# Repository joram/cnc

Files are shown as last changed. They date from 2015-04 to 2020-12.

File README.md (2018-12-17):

# CnC project
This is a scratchpad repos for a homemade CnC machine.

![CnC Image](https://lh3.googleusercontent.com/Xgm548oeinaSXzI4gLVN7XoVqA7QdndGtPZtI5exSCHnF55dnqytLXTcyp7rUA87UzZo4A43uE3hCB0zz5r6ulhqA-s1Z9l3nHRdatXveawGpr5k0o3v1wGfOVFIFiJOtZK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)

## Documentation
- [construction](/docs/construction.md)
- [how to](/docs/how_to.md)
- [gotchas](/docs/gotchas.md)
- [photos](https://photos.app.goo.gl/LfezZGhpHDF61HZo7)

## Potential Future Projects
- button (for test carves)
- alphabet blocks
- wall-o-faces with [photogrammetry](./docs/photogrammetry.md)
- wooden keyboard keys
- replacement plates for CnC machine

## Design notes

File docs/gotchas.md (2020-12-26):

# Gotchas
These are notes around different types of failures in the carving process.

## Grbl not responding
- run the protoneer image [here](https://wiki.protoneer.co.nz/Raspberry_Pi_CNC_User_Interface_SD_Card_Image_V5.00)
- on the desktop there is a script `setup <something>.sh` run it.
- flash hte firmware

## cncjs not starting on boot
setup pm2 as these instructions show [here](https://cnc.js.org/docs/rpi-setup-guide/)

## Axis Slippage
![axis slippage example](https://lh3.googleusercontent.com/Vf0Y8VVEjJ2XM6gfTe-zDjV55Q0uxVouj7I30cJ42lzLdh7OGVdnMimoT3kyHdOLQLK_bFZwpQ-9uzBsDDFnQawyxHjg7FAltyq_YpEZxONzpE0hcR4VNmeD5QOT6cWFXOD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)
This was caused by the axis max speed being configured too fast. Fixed by using grbl console, `$$` to show the settings, and reducing the max speed with $111=200 (setting max y axis speed to be slower).

## Stock Slippage
![stock slippage example](https://lh3.googleusercontent.com/6YKA4u-dw940YjIze_3f_o0F8SFl5KL5prnh7_Do42InjSy5k3oyd3c-yxGbHiALIYOR6loodVLiBiFj7hbNlPa4jSL3y-EL85IqTiSvR1EXWWCtUjLUTIdA_onvhK02feY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)
This was caused by the piece of wood being milled not being fixed securly enough to the bed. Fixed by attaching it securely.

## Stock Tilting
![stock tilting example](https://lh3.googleusercontent.com/TAGg_NbH2bvvy6UUZl_5ei28SwbjK26DU1DIArqDUK3FyZzLX3r0ULFSAph8NOIbOFqiKsIxAeU5NCbYqucJ9vn9xD515G7MOkKrXSUOOhmWLBMeKNv9lEcPw5b-VvpMQmR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)
Same as `Stock Slippage`

## Model Origin (instead of stock)
![model origin example](https://lh3.googleusercontent.com/5Rb-ZSzZFDaninfDXt5FVSv54ZFPO3YPs4qB9GPZXhAcuzTi9tC0n2zDV6-qIzB_at-JtLGqfSBiFv2VKmg3dzT2kL5WLJw5bpFtXIv03030YuJ1XTXKcDOQkVxNNPNzoSa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)
This was caused by selecting part of the model's bounding box as the origin instead of the stock's.
Fixed by picking the origin to be a recognizable edge of the bounding box, with a significant enough headroom on the stock to account for any sort of tilt.

## Why is the toolpath not generating!?
right click mesh, and then "meshg to brep"

## Studdering
Don't randomly turn the potentiometers, you're bound to make it worse. Calibrate the current limit with the instructions.
The Pololu driver docs [here](https://www.pololu.com/product/2133) show
```
To achieve high step rates, the motor supply is typically much higher than would be permissible without active current limiting. For instance, a typical stepper motor might have a maximum current rating of 1 A with a 5Ω coil resistance, which would indicate a maximum motor supply of 5 V. Using such a motor with 12 V would allow higher step rates, but the current must actively be limited to under 1 A to prevent damage to the motor.

The DRV8825 supports such active current limiting, and the trimmer potentiometer on the board can be used to set the current limit. You will typically want to set the driver’s current limit to be at or below the current rating of your stepper motor. One way to set the current limit is to put the driver into full-step mode and to measure the current running through a single motor coil without clocking the STEP input. The measured current will be 0.7 times the current limit (since both coils are always on and limited to approximately 70% of the current limit setting in full-step mode).

Another way to set the current limit is to measure the voltage on the “ref” pin and to calculate the resulting current limit (the current sense resistors are 0.100Ω). The ref pin voltage is accessible on a via that is circled on the bottom silkscreen of the circuit board. The current limit relates to the reference voltage as follows:

Current Limit = VREF × 2

So, for example, if you have a stepper motor rated for 1 A, you can set the current limit to 1 A by setting the reference voltage to 0.5 V.

Note: The coil current can be very different from the power supply current, so you should not use the current measured at the power supply to set the current limit. The appropriate place to put your current meter is in series with one of your stepper motor coils.
```
### For our stepper motors
```
350mA for the nema17 steppers
0.35/2 = vref = 0.175

2.8a for the nema23 stepper
2.8/2 = fref = 1.4

```
## An Axis Stopping Completely
This is because the driver overheated.
We now have heatsinks on the drivers, check that they are still attached.
The current limit may be too high (see how to calibrate in the `Studdering` section), and lower that value a bit.
The side effect of lowering hte vref is that axis provides less power.

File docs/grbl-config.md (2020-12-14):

```
$0=25 (Step pulse time, microseconds)
$1=50 (Step idle delay, milliseconds)
$2=0 (Step pulse invert, mask)
$3=0 (Step direction invert, mask)
$4=0 (Invert step enable pin, boolean)
$5=0 (Invert limit pins, boolean)
$6=0 (Invert probe pin, boolean)
$10=0 (Status report options, mask)
$11=0.010 (Junction deviation, millimeters)
$12=0.002 (Arc tolerance, millimeters)
$13=0 (Report in inches, boolean)
$20=0 (Soft limits enable, boolean)
$21=1 (Hard limits enable, boolean)
$22=0 (Homing cycle enable, boolean)
$23=0 (Homing direction invert, mask)
$24=25.000 (Homing locate feed rate, mm/min)
$25=500.000 (Homing search seek rate, mm/min)
$26=250 (Homing switch debounce delay, milliseconds)
$27=1.000 (Homing switch pull-off distance, millimeters)
$30=1000 (Maximum spindle speed, RPM)
$31=0 (Minimum spindle speed, RPM)
$32=0 (Laser-mode enable, boolean)
$100=50.000 (X-axis travel resolution, step/mm)
$101=100.000 (Y-axis travel resolution, step/mm)
$102=50.000 (Z-axis travel resolution, step/mm)
$110=300.000 (X-axis maximum rate, mm/min)
$111=200.000 (Y-axis maximum rate, mm/min)
$112=200.000 (Z-axis maximum rate, mm/min)
$120=3.000 (X-axis acceleration, mm/sec^2)
$121=3.000 (Y-axis acceleration, mm/sec^2)
$122=3.000 (Z-axis acceleration, mm/sec^2)
$130=1000.000 (X-axis maximum travel, millimeters)
$131=1000.000 (Y-axis maximum travel, millimeters)
$132=15.000 (Z-axis maximum travel, millimeters)
```

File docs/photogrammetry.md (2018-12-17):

# Photogrammetry
The process of taking photos and making a 3D model.

## links
https://www.prusaprinters.org/photogrammetry-3d-scanning-just-phone-camera/
https://demuc.de/colmap/

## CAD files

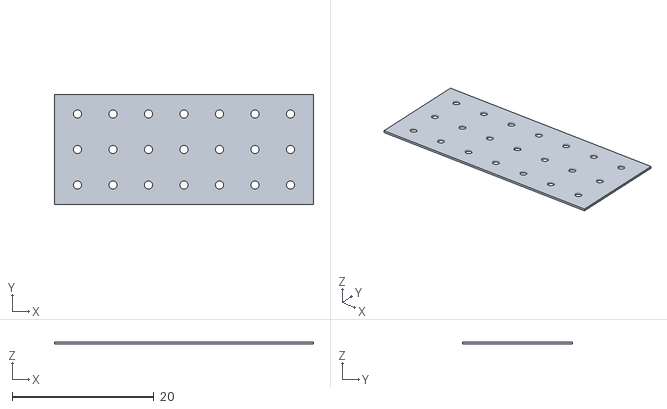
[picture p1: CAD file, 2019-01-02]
gcode/cnc_bed_2.stl
36.5 x 15.5 x 0.3

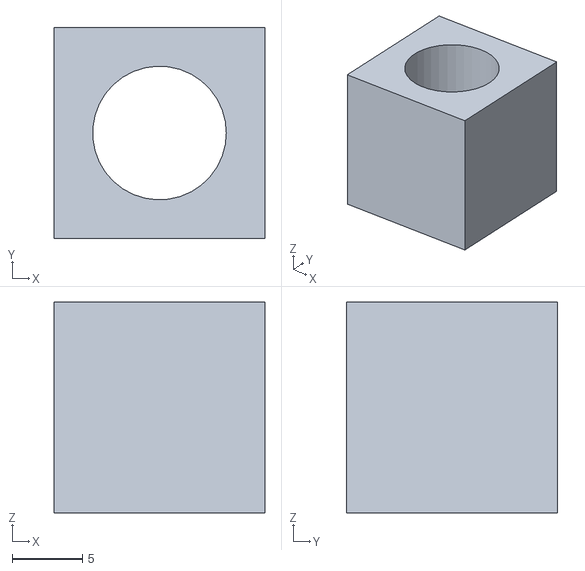
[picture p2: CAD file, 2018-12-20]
gcode/dowl_test.stl
15.0 x 15.0 x 15.0

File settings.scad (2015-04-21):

bed_height = 55; //mm
bed_width = 300; //mm
bed_depth = 300; //mm
y_tray_depth = 80; // mm
nema17_width = 42.2;

//GT2
belt_width=6; 
belt_thickness=5; // ? 
tooth_height=5; // ?
tooth_spacing=2;

// RODS

threaded_rod_diameter = 9;
threaded_rod_diameter_horizontal = 9;
smooth_bar_diameter = 9;
smooth_bar_diameter_horizontal = 9;

// Nuts and bolts

m8_diameter = 9;
m8_nut_diameter = 15.7;

m4_diameter = 5.5;
m4_nut_diameter = 10.6;

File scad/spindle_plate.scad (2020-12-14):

include <components/spindle_mount.scad>;
include <components/sc8uu.scad>;

spindle_plate_w = 150;
spindle_plate_h = 200;
spindle_plate_thickness = 10;

module spindle_plate(show_bolts=false, show_mounts=false){
    dx = spindle_plate_w/2 - sc8uu_l/2;
    dy = spindle_plate_h/2  - sc8uu_w/2;
    dz = -sc8uu_h/2;
    sc8uu_offsets = [
        [ dx,-dy, dz],
        [ dx, dy, dz],
        [-dx,-dy, dz],
        [-dx, dy, dz],
        [  0,  0, dz],
    ];

    if(show_bolts==true){
        translate([0, -spindle_plate_h/4, spindle_plate_thickness]) spindle_mount(true);
        for(t=sc8uu_offsets){
            translate(t) sc8uu(true);
        }
    }
    
    if(show_bolts==false){
        difference(){
            translate([0, 0, spindle_plate_thickness/2]) cube([spindle_plate_w, spindle_plate_h, spindle_plate_thickness], true);
            spindle_plate(true);
        }
    }

    if(show_mounts==true){
        %union(){
            translate([0, -spindle_plate_h/4, spindle_plate_thickness]) union(){
                translate([0,0,spindle_mount_d/2]) spindle();
                spindle_mount();
            }
            for(t=sc8uu_offsets){
                translate(t) sc8uu();
            }
        }
    }

}



//projection(cut = false) translate([spindle_plate_w/2,spindle_plate_h/2,0]) spindle_plate(true, false);
//spindle_plate(false, true);

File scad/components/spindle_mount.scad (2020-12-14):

spindle_d = 52;
spindle_l = 186;
collet_l = 48;
collet_d = 16;

spindle_mount_w = 91;
spindle_mount_h = 41;
spindle_mount_d = 67;


module spindle(){
    translate([0, collet_l-10]) rotate([90]) cylinder(h=spindle_l-collet_l, d=spindle_d, center=true);
    translate([0, -collet_l/2-10]) rotate([90]) cylinder(h=collet_l, d=collet_d, center=true);            
}

module spindle_mount(show_bolts=false){
    bolt_d = 6;
    bolt_x = 77;
    bolt_y = 26;
    offsets = [
        [ bolt_x/2, bolt_y/2],
        [ bolt_x/2,-bolt_y/2],
        [-bolt_x/2, bolt_y/2],
        [-bolt_x/2,-bolt_y/2],
    ];

    if(show_bolts == true){
        translate([0,0,spindle_mount_d/2]) union(){
//            spindle();
            for(t=offsets){
                translate(t) cylinder(h=spindle_mount_d*2, d=bolt_d, center=true);
            }
        }
    }

    // for human eyes only
    if(show_bolts==false){
        difference(){
            translate([0,0,spindle_mount_d/2]) cube([spindle_mount_w, spindle_mount_h, spindle_mount_d], true);
            spindle_mount(true);
        }
    }
}

//spindle_mount();
//%spindle_mount(true);

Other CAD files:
scad/arm-plate.scad
axles.scad
bearings.scad
project.scad
scad/all-plates.scad
scad/components/kp08.scad
scad/components/nema17.scad
scad/components/sc8uu.scad
scad/components/sk8.scad
scad/horizontal-plate.scad
scad/old/axles.scad
scad/old/bearings.scad
scad/old/project.scad
scad/old/settings.scad
scad/old/sliding_tray.scad
scad/vertical-plate.scad
sliding_tray.scad

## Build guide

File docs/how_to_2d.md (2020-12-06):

# How To (2D)

## Make SVG
use your tool of choice
- I've heard inkscape is good
- OR: using any photo editing tool and then converting to svg (web tool [pngtosvg.com](https://www.pngtosvg.com/))
- a 380px square will fit on a alphabet cube.

## Make GCODE
use [jscut.org](http://jscut.org/jscut.html) tool.
- set 300 DPI
- cut depth 0.05 to start, go up to 0.1 per layer
- don't lie about your bit size. it's 3.175 for the default. use calipers if oyu are using a different bit

## Setup Machine
place the block firmly attached to the board
- for small blocks use the clamp
- for big sheets clamp or screw to table

## Mill
- manually drive the bit to the top left corner of your work, barely touching the material.
- zero out the machine
- manually drive the bit to the bottom left of the work (as seen in the UI)
- make sure it will fit the material
- home XY, then home Z
- turn on the spindle
- press play

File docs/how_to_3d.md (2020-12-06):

# How To (3D)
There are three phases to building an object with a CnC machine: modeling, caming, carving

## Modeling
Use whatever you want to make an STL file (or anything that can be imported to fusion 360)

## Caming

## Carving

### Initial setup
- visit [cncJS](http://192.168.1.10:8000) (john with reg password)
- on the left, top right: choose grbl, and connect to ttyS0

### Zero-ing Workspace
There are two coordinate systems: machine and workspace.
Machine origin (0,0,0) is wherever the bit was when the machine was turned on.
Workspace origin is the position in relation to your stock piece (what you are gonna carve).
Before each carve, you want to zero out the workspace origin:
 - reset then unlock
 - keyboard button (to manually control)
 - finger to position for piece you are carving
 - set work position to zero/zero/zero

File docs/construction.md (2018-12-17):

## Parts List

### Electronic
|  name | #  |  unit cost  | total cost |
|:---|---:|---|---|
| nema17 stepper motors | 3x | [$00.00](https://www.adafruit.com/product/324) ||
| milling motor | 1x | [here]() ||
| Raspberry PI 3 | 1x | [here](https://www.amazon.ca/gp/product/B01CD5VC92/ref=oh_aui_detailpage_o01_s00?ie=UTF8&psc=1) ||
| CnC Controller | 1x | [here](https://www.buyapi.ca/product/raspberry-pi-cnc-board/) ||
| Stepper Motor Controller | 1x | [here](https://www.pololu.com/product/2133) ||
| Stepper power supply | 1x | [here](https://www.amazon.ca/gp/product/B00FEYHNIE/ref=oh_aui_detailpage_o00_s00?ie=UTF8&psc=1) ||
| Drill power supply | 1x | [here](https://www.amazon.ca/gp/product/B0716XVR7P/ref=oh_aui_detailpage_o00_s00?ie=UTF8&psc=1) ||

### Hardware
| name |  #  | unit cost | total cost |
|---:|:----|---|---|
| aluminium beams | 12x | [here](https://www.adafruit.com/product/1221) | |
| stepper axle adapter | 3x  | [here](https://www.adafruit.com/product/1176) ||
| t-slot nuts | 1x  | [here]() ||
| bolts | 1x  | [here]() ||
| corner bracket | 1x  | [here]() ||
| corner triangle | 1x  | [here]() ||
| sheet of plastic | 1x  | [here]() ||
| long threaded axle | 2x  | [here]() ||
| short threaded axle  | 1x  | [here]() ||
| short threaded axle  | 1x  | [here]() ||

## Construction Gotchas
- a moving gantry powered by two axles was hard
    - a fixed gantry and moving piece plate was easier

## Software
There are two stages in making a physical object: `stl` then `gcode`.
Following that, we use the cnc controller via a web interface to do the milling.
### Designing
- *STL* - for athetic pieces [blender](https://www.blender.org)
- *STL* - for mechanical pieces [openSCAD](www.openscad.org)
- *GCode* - [visualCADCAM]()
- *Preview* - [CAMotics]()
### Carving
- *web interface* - [CNCjs]()
- *grbl* - [grbl]()

## RPi setup
```
mkdir ~/code
cd ~/code
sudo apt-get update
sudo apt-get install -y git avrdude
sudo apt-get install -y realvnc-vnc-server realvnc-vnc-viewer
git clone git@github.com:vlachoudis/bCNC.git
git clone git@github.com:Protoneer/RPI-CNC-Config-Scripts.git
source ~/code/RPIa-CNC-Config-Scripts/resources/scripts/Run-Flash-GRBL-Latest.sh
```

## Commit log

2015-04-20 settings and basic axles.
    [axles.scad, settings.scad]
2015-04-20 nema17 stepper motor shape, and mounting plate.
    [nema17.scad]
2015-04-20 full project file, along with seperated parts.
    [axles.scad, nema17.scad, project.scad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]
2015-04-21 Y axis stepper mount.
    [axles.scad, bearings.scad, nema17.scad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]
2015-04-22 restarting with centered objects
    [axles.scad, bearings.scad, project.scad]
2015-04-23 aligned linear bearing to (0, 0, 0)
    [bearings.scad, project.scad]
2015-04-23 sliding plate aligned with (0,0,0)
    [bearings.scad, project.scad]
2015-04-24 nema17 mount plate
    [nema17.scad, sliding_tray.scad]
2016-12-21 adding arm-plate
    [arm-plate.scad]
2016-12-24 vertical plate updates
    [arm-plate.scad]
2016-12-25 added final plate (horizontal plate)
    [arm-plate.scad, axles.scad, bearings.scad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]
2017-01-06 exported stl
    [all-plates.scad, horizontal-plate.scad, sk8.scad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]
2017-09-17 rpi setup script
    [all-plates.scad, arm-plate.scad, axles.scad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]
2018-12-17 adding button gcode, and updating docs
2018-12-17 Rename button #2.nc to button #2.gcode
2020-12-14 all plates together in one scad file to prove they will work together.
    [all-plates.scad, arm-plate.scad, horizontal-plate.scad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]
